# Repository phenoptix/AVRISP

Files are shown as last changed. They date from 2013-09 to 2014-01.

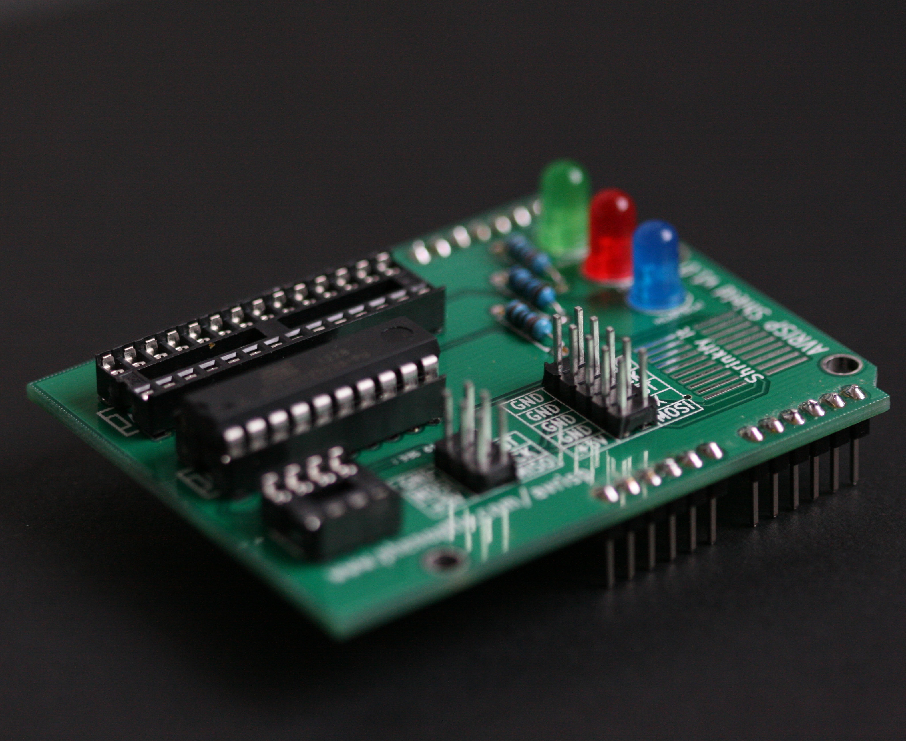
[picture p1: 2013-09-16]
AVR ISP Built.jpg

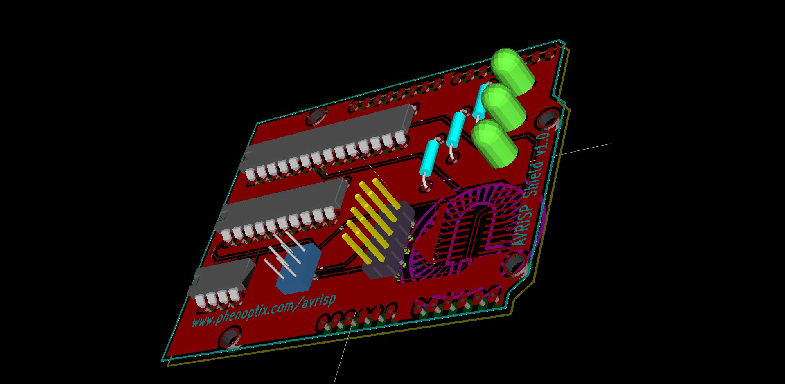
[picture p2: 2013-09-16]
AVR ISP.jpg

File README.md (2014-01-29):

AVR ISP Shield for Arduino
===========================
[AVR ISP Shield of Arduino  
AVR ISP Shield for Arduino](http://www.phenoptix.com/avrisp)

This is an AVR ISP Shield for Arduino

Repository Contents
-------------------
* **/Hardware** - Kicad PCB .pro .sch and .brb files and PDF of Schematic
* **/Software** - Arduino Sketch for Using the Board

Version History
---------------
* V0.1 Functions well for the ATTiny85 but seem to be having problems with the ATMega328 - working on it!
* V1.0 Fully working - has a rearrange from previous versions which avoids grounding on the USB connector on an Uno.

License Information
-------------------
The hardware is released under [Creative Commons Share-alike 3.0](http://creativecommons.org/licenses/by-sa/3.0/).  
All other code is open source so please feel free to do anything you want with it; you buy me a beer if you use this and we meet someday ([Beerware license](http://en.wikipedia.org/wiki/Beerware)).
Also this boiler plate is yoinked from Sparkfun with thanks.

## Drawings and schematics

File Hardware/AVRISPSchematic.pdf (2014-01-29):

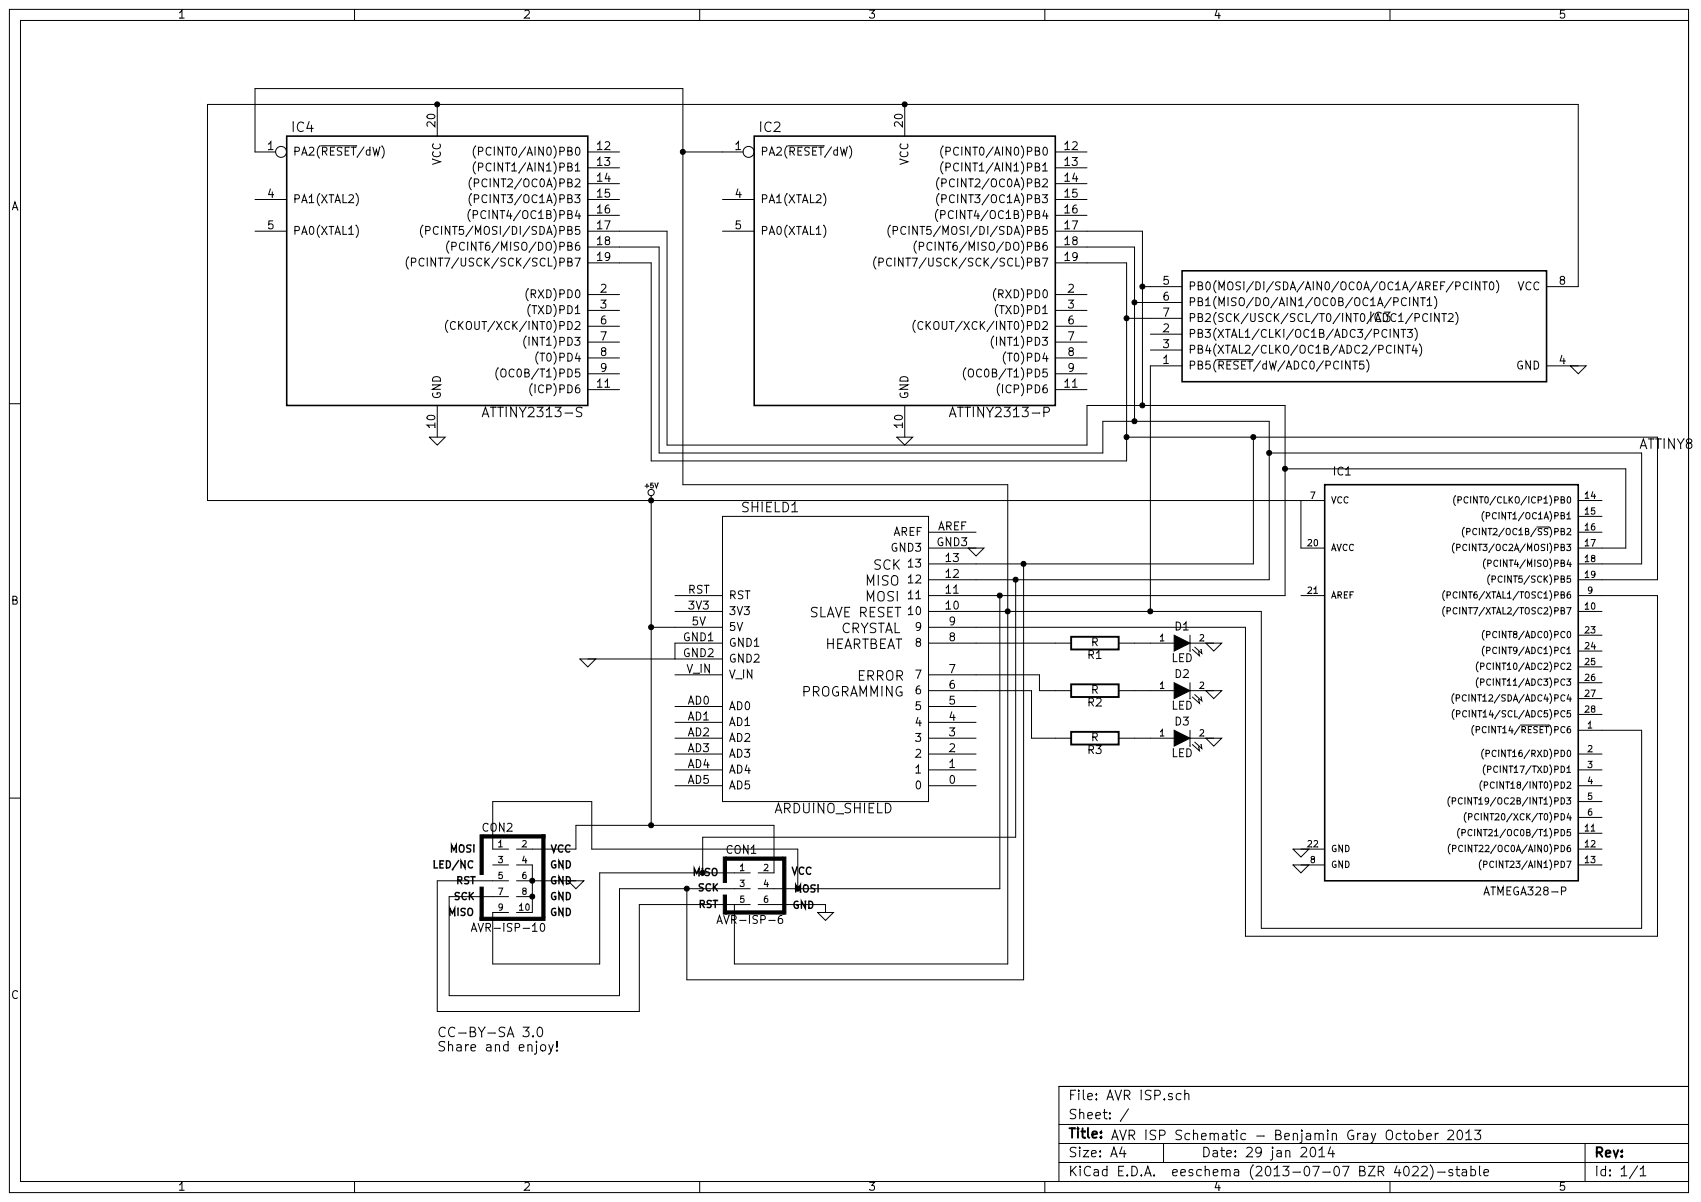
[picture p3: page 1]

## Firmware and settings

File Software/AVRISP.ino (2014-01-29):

// this sketch turns the Arduino into a AVRISP
// using the following pins:
// 10: slave reset
// 11: MOSI
// 12: MISO
// 13: SCK

// Put an LED (with resistor) on the following pins:
//  7: Error - Lights up if something goes wrong (use red if that makes sense)
//  8: Programming - In communication with the slave
//  6: Heartbeat - shows the programmer is running (removed, see notes below)
// Optional - Piezo speaker on pin A3
//
// October 2009 by David A. Mellis
// - Added support for the read signature command
// 
// February 2009 by Randall Bohn
// - Added support for writing to EEPROM (what took so long?)
// Windows users should consider WinAVR's avrdude instead of the
// avrdude included with Arduino software.
//
// January 2008 by Randall Bohn
// - Thanks to Amplificar for helping me with the STK500 protocol
// - The AVRISP/STK500 (mk I) protocol is used in the arduino bootloader
// - The SPI functions herein were developed for the AVR910_ARD programmer 
// - More information at http://code.google.com/p/mega-isp
//
// March 2012 - William Phelps
// modify to work with Arduino IDE 1.0 which has a shorter serial port receive buffer
// getEOP() now gets entire request before avrisp() is called to process it
// Serial.print((char) xxx) changed to Serial.write(xxx)
// uint8_t changed to byte
// added support for Piezo speaker
// moved Pmode LED to A0
// removed "heartbeat" on pin 6, added short blip of ERROR LED instead 
// Why is it that PROG_FLASH and PROG_DATA don't actually do anything???
// Tested with Arduino IDE 22 and 1.0
// IDE 22 - 5148 bytes
// IDE 1.0 - 5524 bytes!

// January 2014 - Ben Gray
// Put the heartbeat LED back and switched around the pins a little for the LEDs.


// SLOW SPEED CHIP ERASE AND FUSE BURNING
//
// Enable LOW_SPEED to allow you to erase chips that would fail otherwise,
// for being running with a clock too slow for the programmer.
//
// This allowed me to recover several ATMega328 that had no boot loader and the
// first instruction was to set the clock to the slowest speed. Usually this
// kind of recovery requires high voltage programming, but this trick will do
// just fine.
//
// How to proceed:
// 1. Enable LOW_SPEED, and load it to the programmer.
// 2. Erase and burn the fuses on the target uC. Example for ATMega328:
//   arduino-1.0.1/hardware/tools/avrdude -Carduino-1.0.1/hardware/tools/avrdude.conf -patmega328p -cstk500v1 -P /dev/serial/by-id/usb-FTDI_FT232R_USB_UART_A900cf1Q-if00-port0 -b19200 -e -Ulock:w:0x3F:m -Uefuse:w:0x05:m -Uhfuse:w:0xDA:m -Ulfuse:w:0xF7:m
// 3. Comment LOW_SPEED and load it back to the programmer.
// 4. Program the target uC as usual. Example:
//  arduino-1.0.1/hardware/tools/avrdude -Carduino-1.0.1/hardware/tools/avrdude.conf -patmega328p -cstk500v1 -P /dev/serial/by-id/usb-FTDI_FT232R_USB_UART_A900cf1Q-if00-port0 -b19200 -Uflash:w:firmware.hex:i 
//
// Note 1: EXTRA_SPI_DELAY was added to let you slow down SPI even more. You can
// play with the value if it does not work with the default.
// Note 2: LOW_SPEED will alow you only to erase the chip and burn the fuses! It
// will fail if you try to program the target uC this way!

//#define LOW_SPEED
#ifdef LOW_SPEED
#define EXTRA_SPI_DELAY 125
#else
#define EXTRA_SPI_DELAY 0
#endif

#include "pins_arduino.h"  // defines SS,MOSI,MISO,SCK
#define RESET SS

#define LED_ERR 7
#define LED_PMODE 8
#define LED_HB 6
//#define PIEZO A3

#define HWVER 2
#define SWMAJ 1
#define SWMIN 18

// STK Definitions
const byte STK_OK = 0x10;
const byte STK_FAILED = 0x11;
const byte STK_UNKNOWN = 0x12;
const byte STK_INSYNC = 0x14;
const byte STK_NOSYNC = 0x15;
const byte CRC_EOP = 0x20; //ok it is a space...

const byte STK_GET_SYNC     = 0x30;
const byte STK_GET_SIGNON   = 0x31;
const byte STK_GET_PARM     = 0x41;
const byte STK_SET_PARM     = 0x42;
const byte STK_SET_PARM_EXT = 0x45;
const byte STK_PMODE_START  = 0x50;
const byte STK_PMODE_END    = 0x51;
const byte STK_SET_ADDR     = 0x55;
const byte STK_UNIVERSAL    = 0x56;
const byte STK_PROG_FLASH   = 0x60;
const byte STK_PROG_DATA    = 0x61;
const byte STK_PROG_PAGE    = 0x64;
const byte STK_READ_PAGE    = 0x74;
const byte STK_READ_SIGN    = 0x75;

//// TONES  ==========================================
//// Start by defining the relationship between
////       note, period, &  frequency.
//#define  c     3830    // 261 Hz
//#define  d     3400    // 294 Hz
//#define  e     3038    // 329 Hz
//#define  f     2864    // 349 Hz
//#define  g     2550    // 392 Hz
//#define  a     2272    // 440 Hz
//#define  b     2028    // 493 Hz
//#define  C     1912    // 523 Hz 

//void pulse(int pin, int times);

int error=0;
int pmode=0;
// address for reading and writing, set by STK_SET_ADDR command
int _addr;
byte _buffer[256]; // serial port buffer
int pBuffer = 0;  // buffer pointer
int iBuffer = 0;  // buffer index
byte buff[256];  // temporary buffer
boolean EOP_SEEN = false;

void setup() {

  Serial.begin(19200);
//  pinMode(PIEZO, OUTPUT);
//  beep(1700, 40);
  EOP_SEEN = false;
  iBuffer = pBuffer = 0;

  pinMode(LED_PMODE, OUTPUT);
  pulse(LED_PMODE, 2);
  pinMode(LED_ERR, OUTPUT);
  pulse(LED_ERR, 2);
  pinMode(LED_HB, OUTPUT);
  pulse(LED_HB, 2);
  
  pinMode(9, OUTPUT);
  // setup high freq PWM on pin 9 (timer 1)
  // 50% duty cycle -> 8 MHz
  OCR1A = 0;
  ICR1 = 1;
  // OC1A output, fast PWM
  TCCR1A = _BV(WGM11) | _BV(COM1A1);
  TCCR1B = _BV(WGM13) | _BV(WGM12) | _BV(CS10); // no clock prescale
  
 
}

#define beget16(addr) (*addr * 256 + *(addr+1) )
typedef struct param {
  byte devicecode;
  byte revision;
  byte progtype;
  byte parmode;
  byte polling;
  byte selftimed;
  byte lockbytes;
  byte fusebytes;
  int flashpoll;
  int eeprompoll;
  int pagesize;
  int eepromsize;
  int flashsize;
} 
parameter;

parameter param;

// this provides a heartbeat on pin 6, so you can tell the software is running.
byte hbval=128;
int8_t hbdelta=4;
void heartbeat() {
  if (hbval > 192) hbdelta = -hbdelta;
  if (hbval < 32) hbdelta = -hbdelta;
  if (hbval > 250) hbdelta = -hbdelta;
  if (hbval < 10) hbdelta = -hbdelta;
  hbval += hbdelta;
  analogWrite(LED_HB, hbval);
  delay(20);
}
  
void getEOP() {
  int minL = 0;
  byte avrch = 0;
  byte bl = 0;
  while (!EOP_SEEN) {
    while (Serial.available()>0) {
      byte ch = Serial.read();
      _buffer[iBuffer] = ch;
      iBuffer = (++iBuffer)%256;  // increment and wrap
      if (iBuffer == 1)  avrch = ch;  // save command
      if ((avrch == STK_PROG_PAGE) && (iBuffer==3)) {
        minL = 256*_buffer[1] + _buffer[2] + 4;
      }
      if ((iBuffer>minL) && (ch == CRC_EOP)) {
        EOP_SEEN = true;
      }
    }
    if (!EOP_SEEN) {
      heartbeat(); // light the heartbeat LED
 //     if (bl == 100) {
 //       pulse(LED_ERR,1,10);  // blink the red LED
 //       bl = 0;
 //     }
      bl++;
      delay(10);
    }
  }
}

// serialEvent not used so sketch would be compatible with older IDE versions
//void serialEvent() {
//  int minL = 0;
//  byte avrch = 0;
//  while (Serial.available()>0)
//  {
//    byte ch = Serial.read();
//    _buffer[iBuffer] = ch;
//    iBuffer = (++iBuffer)%256;  // increment and wrap
//    if (iBuffer == 1)  avrch = ch;  // save command
//    if ((avrch == STK_PROG_PAGE) && (iBuffer==3)) {
//      minL = 256*_buffer[1] + _buffer[2] + 4;
//    }
//    if ((iBuffer>minL) && (ch == CRC_EOP)) {
//      EOP_SEEN = true;
//    }
//  }
//}

void loop(void) {
  // is pmode active?
//  if (pmode) digitalWrite(LED_PMODE, HIGH); 
//  else digitalWrite(LED_PMODE, LOW);
  digitalWrite(LED_PMODE, LOW);
  // is there an error?
  if (error) digitalWrite(LED_ERR, HIGH); 
  else digitalWrite(LED_ERR, LOW);

  getEOP();
  
  // have we received a complete request?  (ends with CRC_EOP)
  if (EOP_SEEN) {
    digitalWrite(LED_PMODE, HIGH);
    EOP_SEEN = false;
    avrisp();
    iBuffer = pBuffer = 0;  // restart buffer
  }
  
}

byte getch() {
  if (pBuffer == iBuffer) {  // spin until data available ???
    pulse(LED_ERR, 1);
//    beep(1700, 20);
    error++;
    return -1;
  }
  byte ch = _buffer[pBuffer];  // get next char
  pBuffer = (++pBuffer)%256;  // increment and wrap
  return ch;
}

void readbytes(int n) {
  for (int x = 0; x < n; x++) {
    buff[x] = getch();
  }
}

//#define PTIME 20
void pulse(int pin, int times, int ptime) {
  do {
    digitalWrite(pin, HIGH);
    delay(ptime);
    digitalWrite(pin, LOW);
    delay(ptime);
    times--;
  } 
  while (times > 0);
}
void pulse(int pin, int times) {
  pulse(pin, times, 50);
}

void spi_init() {
  byte x;
  SPCR = 0x53;
#ifdef LOW_SPEED
SPCR=SPCR|B00000011;
#endif
  x=SPSR;
  x=SPDR;
}

void spi_wait() {
  do {
  } 
  while (!(SPSR & (1 << SPIF)));
}

byte spi_send(byte b) {
  byte reply;
#ifdef LOW_SPEED
    cli();
    CLKPR=B10000000;
    CLKPR=B00000011;
    sei();
#endif
  SPDR=b;
  spi_wait();
  reply = SPDR;
#ifdef LOW_SPEED
    cli();
    CLKPR=B10000000;
    CLKPR=B00000000;
   sei();
#endif
    return reply;
}

byte spi_transaction(byte a, byte b, byte c, byte d) {
  byte n;
  spi_send(a); 
  n=spi_send(b);
  //if (n != a) error = -1;
  n=spi_send(c);
  return spi_send(d);
}

void replyOK() {
//  if (EOP_SEEN == true) {
  if (CRC_EOP == getch()) {  // EOP should be next char
    Serial.write(STK_INSYNC);
    Serial.write(STK_OK);
  } 
  else {
    pulse(LED_ERR, 2);
    Serial.write(STK_NOSYNC);
    error++;
  }
}

void breply(byte b) {
  if (CRC_EOP == getch()) {  // EOP should be next char
    Serial.write(STK_INSYNC);
    Serial.write(b);
    Serial.write(STK_OK);
  } 
  else {
    Serial.write(STK_NOSYNC);
    error++;
  }
}

void get_parameter(byte c) {
  switch(c) {
  case 0x80:
    breply(HWVER);
    break;
  case 0x81:
    breply(SWMAJ);
    break;
  case 0x82:
    breply(SWMIN);
    break;
  case 0x93:
    breply('S'); // serial programmer
    break;
  default:
    breply(0);
  }
}

void set_parameters() {
  // call this after reading paramter packet into buff[]
  param.devicecode = buff[0];
  param.revision = buff[1];
  param.progtype = buff[2];
  param.parmode = buff[3];
  param.polling = buff[4];
  param.selftimed = buff[5];
  param.lockbytes = buff[6];
  param.fusebytes = buff[7];
  param.flashpoll = buff[8]; 
  // ignore buff[9] (= buff[8])
  //getch(); // discard second value
  
  // WARNING: not sure about the byte order of the following
  // following are 16 bits (big endian)
  param.eeprompoll = beget16(&buff[10]);
  param.pagesize = beget16(&buff[12]);
  param.eepromsize = beget16(&buff[14]);

  // 32 bits flashsize (big endian)
  param.flashsize = buff[16] * 0x01000000
    + buff[17] * 0x00010000
    + buff[18] * 0x00000100
    + buff[19];

}

void start_pmode() {
  spi_init();
  // following delays may not work on all targets...
  pinMode(RESET, OUTPUT);
  digitalWrite(RESET, HIGH);
  pinMode(SCK, OUTPUT);
  digitalWrite(SCK, LOW);
  delay(50+EXTRA_SPI_DELAY);
  digitalWrite(RESET, LOW);
  delay(50+EXTRA_SPI_DELAY);
  pinMode(MISO, INPUT);
  pinMode(MOSI, OUTPUT);
  spi_transaction(0xAC, 0x53, 0x00, 0x00);
  pmode = 1;
}

void end_pmode() {
  pinMode(MISO, INPUT);
  pinMode(MOSI, INPUT);
  pinMode(SCK, INPUT);
  pinMode(RESET, INPUT);
  pmode = 0;
}

void universal() {
//  int w;
  byte ch;
//  for (w = 0; w < 4; w++) {
//    buff[w] = getch();
//  }
  readbytes(4);
  ch = spi_transaction(buff[0], buff[1], buff[2], buff[3]);
  breply(ch);
}

void flash(byte hilo, int addr, byte data) {
  spi_transaction(0x40+8*hilo, addr>>8 & 0xFF, addr & 0xFF, data);
}
void commit(int addr) {
  spi_transaction(0x4C, (addr >> 8) & 0xFF, addr & 0xFF, 0);
}

//#define _current_page(x) (here & 0xFFFFE0)
int current_page(int addr) {
  if (param.pagesize == 32) return addr & 0xFFFFFFF0;
  if (param.pagesize == 64) return addr & 0xFFFFFFE0;
  if (param.pagesize == 128) return addr & 0xFFFFFFC0;
  if (param.pagesize == 256) return addr & 0xFFFFFF80;
  return addr;
}
byte write_flash(int length) {
  if (param.pagesize < 1) {
    return STK_FAILED;
  }
  //if (param.pagesize != 64) return STK_FAILED;
  int page = current_page(_addr);
  int x = 0;
  while (x < length) {
    if (page != current_page(_addr)) {
      commit(page);
      page = current_page(_addr);
    }
    flash(LOW, _addr, buff[x++]);
    flash(HIGH, _addr, buff[x++]);
    _addr++;
  }
  commit(page);
  return STK_OK;
}

byte write_eeprom(int length) {
  // here is a word address, so we use here*2
  // this writes byte-by-byte,
  // page writing may be faster (4 bytes at a time)
  for (int x = 0; x < length; x++) {
    spi_transaction(0xC0, 0x00, _addr*2+x, buff[x]);
    delay(45);
  } 
  return STK_OK;
}

void program_page() {
  byte result = STK_FAILED;
  int length = 256 * getch() + getch();
  if (length > 256) {
      Serial.write(STK_FAILED);
      error++;
      return;
  }
  char memtype = (char)getch();
//  for (int x = 0; x < length; x++) {
//    buff[x] = getch();
//  }
  readbytes(length);
  if (CRC_EOP == getch()) {
    Serial.write(STK_INSYNC);
    switch (memtype) {
      case 'E':
        result = (byte)write_eeprom(length);
        break;
      case 'F':
        result = (byte)write_flash(length);
        break;
    }
    Serial.write(result);
    if (result != STK_OK) {
      error++;
    }
  } 
  else {
    Serial.write(STK_NOSYNC);
    error++;
  }
}

byte flash_read(byte hilo, int addr) {
  return spi_transaction(0x20 + hilo * 8,
    (addr >> 8) & 0xFF,
    addr & 0xFF,
    0);
}

char flash_read_page(int length) {
  for (int x = 0; x < length; x+=2) {
    byte low = flash_read(LOW, _addr);
    Serial.write( low);
    byte high = flash_read(HIGH, _addr);
    Serial.write( high);
    _addr++;
  }
  return STK_OK;
}

char eeprom_read_page(int length) {
  // here again we have a word address
  for (int x = 0; x < length; x++) {
    byte ee = spi_transaction(0xA0, 0x00, _addr*2+x, 0xFF);
    Serial.write( ee);
  }
  return STK_OK;
}

void read_page() {
  byte result = (byte)STK_FAILED;
  int length = 256 * getch() + getch();
  char memtype = getch();
  if (CRC_EOP != getch()) {
    Serial.write(STK_NOSYNC);
    return;
  }
  Serial.write(STK_INSYNC);
  if (memtype == 'F') result = flash_read_page(length);
  if (memtype == 'E') result = eeprom_read_page(length);
  Serial.write(result);
  return;
}

void read_signature() {
  if (CRC_EOP != getch()) {
    Serial.write(STK_NOSYNC);
    error++;
    return;
  }
  Serial.write(STK_INSYNC);
  byte high = spi_transaction(0x30, 0x00, 0x00, 0x00);
  Serial.write(high);
  byte middle = spi_transaction(0x30, 0x00, 0x01, 0x00);
  Serial.write(middle);
  byte low = spi_transaction(0x30, 0x00, 0x02, 0x00);
  Serial.write(low);
  Serial.write(STK_OK);
}
//////////////////////////////////////////
//////////////////////////////////////////


////////////////////////////////////
////////////////////////////////////

int avrisp() { 
  byte data, low, high;
  byte avrch = getch();
  switch (avrch) {
    case STK_GET_SYNC: // get in sync
      replyOK();
      break;
    case STK_GET_SIGNON:  // get sign on
      if (getch() == CRC_EOP) {
        Serial.write(STK_INSYNC);
        Serial.write("AVR ISP");
        Serial.write(STK_OK);
      }
      break;
    case STK_GET_PARM:  // 0x41
      get_parameter(getch());
      break;
    case STK_SET_PARM:  // 0x42
      readbytes(20);
      set_parameters();
      replyOK();
      break;
    case STK_SET_PARM_EXT: // extended parameters - ignore for now
      readbytes(5);
      replyOK();
      break;
    case STK_PMODE_START:  // 0x50
 //     beep(2272, 20);
      start_pmode();
      replyOK();
      break;
    case STK_PMODE_END:  //0x51
//      beep(1912, 50);
      error=0;
      end_pmode();
      replyOK();
      break;
    case STK_SET_ADDR:  // 0x55
      _addr = getch() + 256 * getch();
      replyOK();
      break;
    case STK_UNIVERSAL:  //UNIVERSAL 0x56
      universal();
      break;
    case STK_PROG_FLASH: //STK_PROG_FLASH  ???
      low = getch();
      high = getch();
      replyOK();
      break;
    case STK_PROG_DATA: //STK_PROG_DATA  ???
      data = getch();
      replyOK();
      break;
    case STK_PROG_PAGE:  //STK_PROG_PAGE
//      beep(1912, 20);
      program_page();
      break;
    case STK_READ_PAGE: //STK_READ_PAGE
      read_page();    
      break;
    case STK_READ_SIGN: //STK_READ_SIGN
      read_signature();
      break;
    // expecting a command, not CRC_EOP
    // this is how we can get back in sync
    case CRC_EOP:
      Serial.write(STK_NOSYNC);
      break;
    // anything else we will return STK_UNKNOWN
    default:
      if (CRC_EOP == getch()) 
        Serial.write(STK_UNKNOWN);
      else
        Serial.write(STK_NOSYNC);
  }
}

// beep without using PWM
//void beep(int tone, long duration){
//  long elapsed = 0;
//  while (elapsed < (duration * 10000)) {
//    digitalWrite(PIEZO, HIGH);
//    delayMicroseconds(tone / 2);
//    digitalWrite(PIEZO, LOW);
//    delayMicroseconds(tone / 2);
    // Keep track of how long we pulsed
//    elapsed += tone;
//  } 
//}  

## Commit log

2013-08-25 Single Sided Board Layout + Footprints
    Things left to do. ISP Header needs checking. Think pins are wrong. Also
    need SMD Footprint for ATTiny85, possibly even a 2313 if it's a dil
    style chip.
    [$AVR ISP.sch, AVR ISP.brd]
2013-08-25 Modified Schematic
    [$AVR ISP.brd, $AVR ISP.sch, AVR ISP.sch]
2013-08-26 Added SMD Footprint and 10-Pin header
    [$AVR ISP.brd, $AVR ISP.sch, AVR ISP.brd]
2013-08-26 connected new stuff
    [$AVR ISP.sch, AVR ISP.brd, AVR ISP.sch]
2013-09-02 Logos added and ATTiny85 Moved.
    Also added ground to the soic at pin 4 for ATTiny85 programming and
    moved the ISP Headers to allow me to put a massive logo on the back.
    [$AVR ISP.sch, AVR ISP.brd, AVR ISP.sch]
2013-09-02 After head problems
    [AVR ISP.brd]
2013-10-16 Switched Components around to avoid grounding
    [$AVR ISP.sch, AVR ISP.brd]
2014-01-29 Housekeeping
    Reorganisation Update and Added PDF
    [AVR ISP.brd, AVR ISP.sch]
